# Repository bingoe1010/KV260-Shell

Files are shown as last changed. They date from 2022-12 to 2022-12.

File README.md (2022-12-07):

# KV260 Shell

<p align="center">
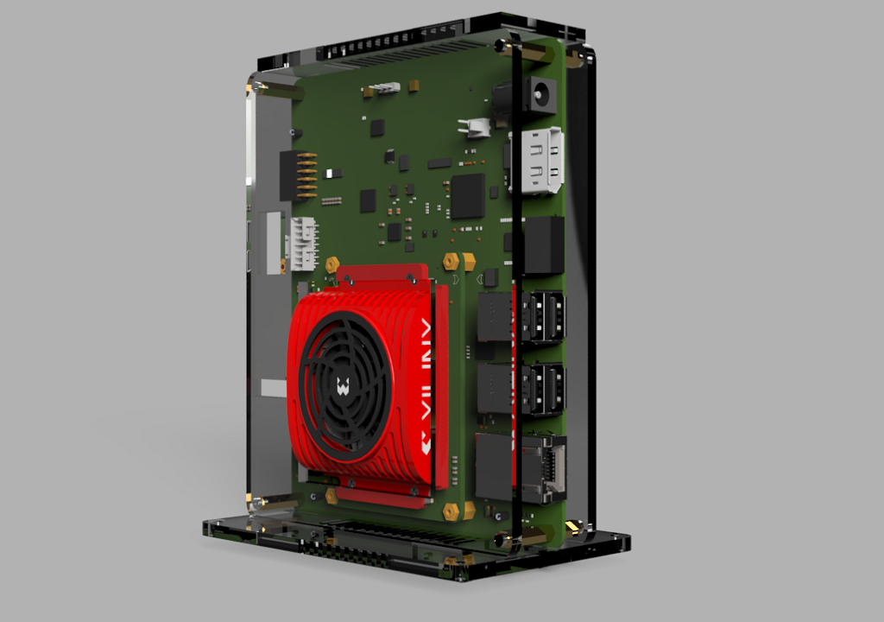
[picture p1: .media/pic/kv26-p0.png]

</p>

> This project is a vertical enclosure for a KV260 development board. The model is drawn using Fusion360 Education Edition, and the shell material can be 4mm acrylic or 3D printed structural parts. The overall cost of using the acrylic version can be controlled within 45RMB (20 RMB for acrylic material processing; Screw copper pillar about 20RMB)

[:star::star::star:中文本版介绍说明](./README_cn.md)

**3D model rendering**

<p align="center">
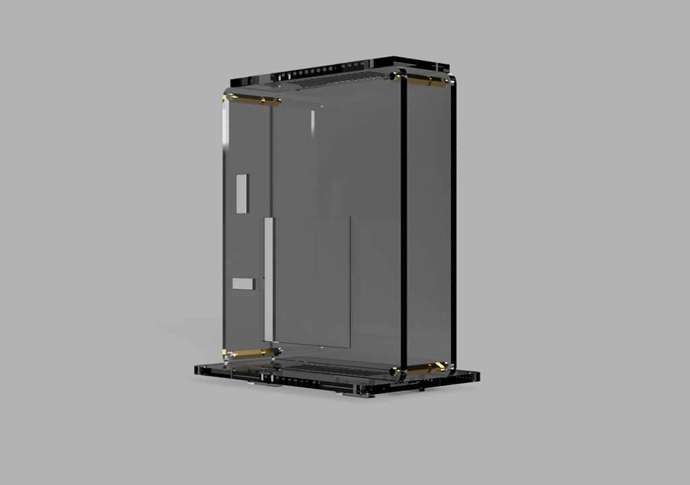
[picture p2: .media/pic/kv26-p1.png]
    
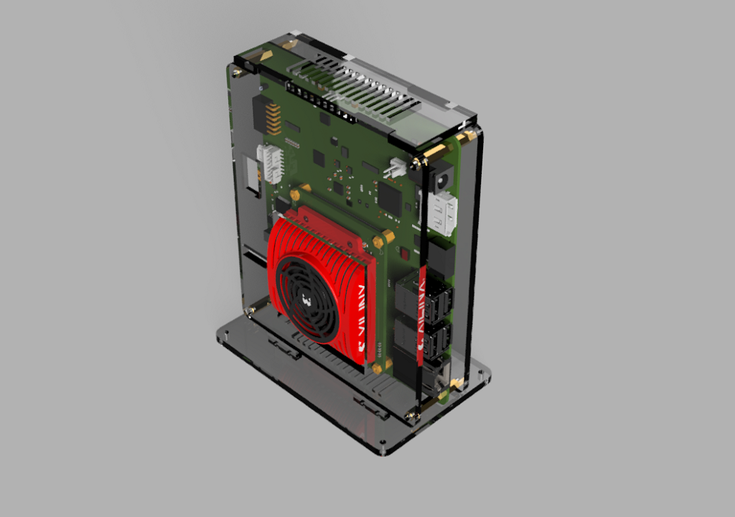
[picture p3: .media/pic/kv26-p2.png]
    
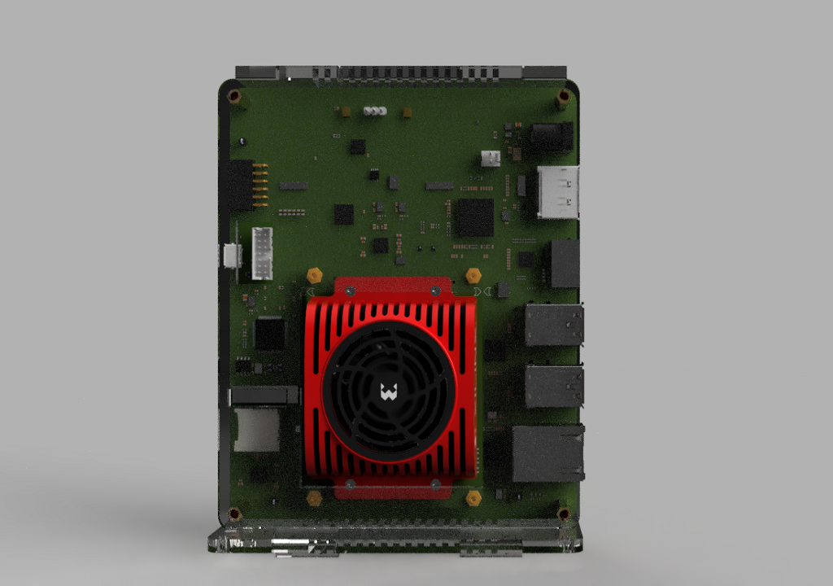
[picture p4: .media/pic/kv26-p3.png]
    
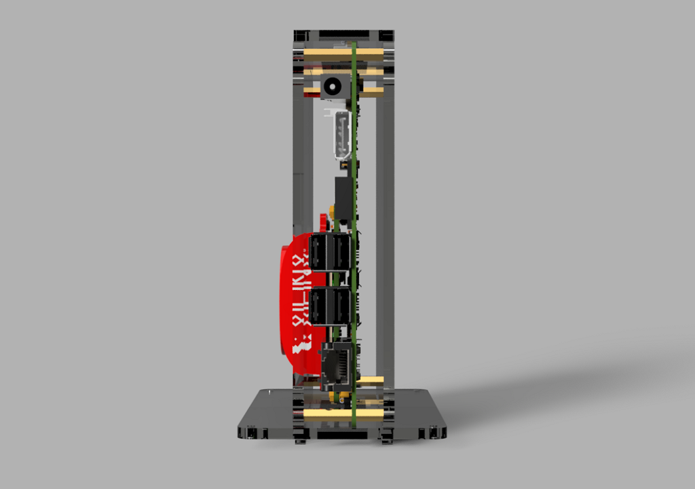
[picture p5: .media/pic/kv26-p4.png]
    
    <br>
    <sup>3D-view drawing<a href="http://https://github.com/bingxie-xpu/" target="_blank">Author:bingxie</a></sup>
</p>

## Content

1. [Description](#Description)

2. [Instruction](#Instruction)

3. [Required](#Required)

4. [Exhibition](#Exhibition)

## Description

|  **Item**  | **Description** | **Other** |
| :---: | :---: | :---: |
| **.media** | Media illustration folder | .png/.gif |
| **1.Doc**  | Details of the required copper pillar screws | .xlsx |
| **2.Stl**  | 3D printed model files | .stl |
| **3.Dxf**  | Acrylic plate cutting file | .dxf |

## Instruction

Video Link：[【KV260系列】KV260立式亚克力外壳制作](https://www.bilibili.com/video/BV1s44y1S7Lj/?vd_source=3a0f8ef7e33855035b7b41686470a16f)

```tcl
https://www.bilibili.com/video/BV1s44y1S7Lj/?vd_source=3a0f8ef7e33855035b7b41686470a16f
```

## Required

* Acrylic sheet (or 3D printed structural parts)

All DXF cutting files are in the project directory under `3. Dxf`, where `kv26_all-V2.dxf` is a two-dimensional machining diagram of all plates, as shown in the figure below. The rest of the files are 2D drawings of individual parts that you can use to build the 3D model you need.

<p align="center">
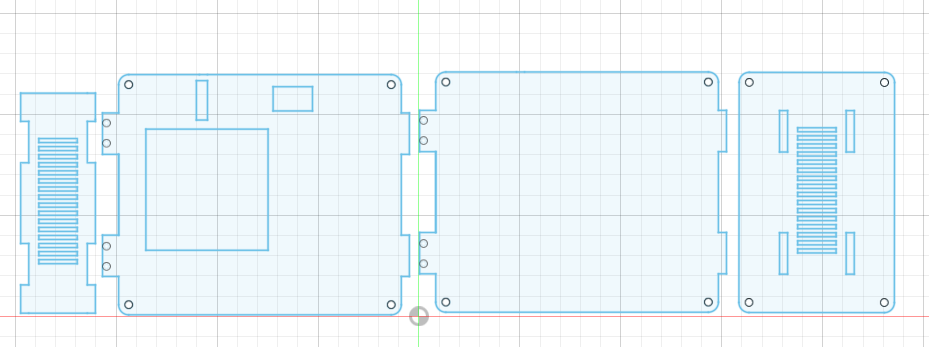
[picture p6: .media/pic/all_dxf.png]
    
    <br>
    <sup>kv26_all-V2.dxf  <a href="http://https://github.com/bingxie-xpu/" target="_blank">Author:bingxie</a></sup>
</p>

Tips.  From the left to right is`top_shell`、`front_shell`、`back_shell`、`base_shell`

* The model and quantity of copper pillar screws are shown in the following table:

| **Pattern** | **Name** | **Specification** | **Number** |
| :---: | :---: | :---: | :---: |
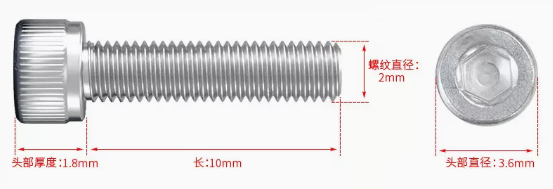
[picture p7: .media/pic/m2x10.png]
|   | **内六角螺丝** | `M2x10` | 8 |
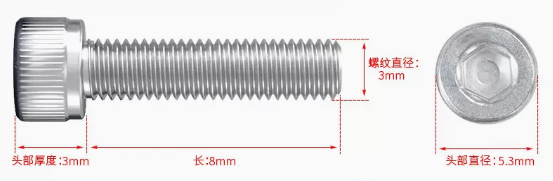
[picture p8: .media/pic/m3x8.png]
|  | **内六角螺丝** | `M3x8` | 12 |
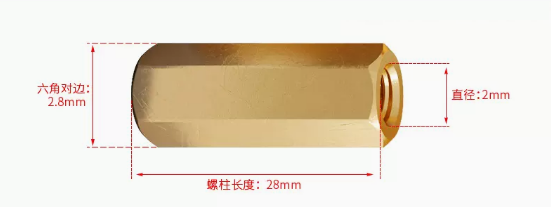
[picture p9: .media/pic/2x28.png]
|  |  **六角双通铜柱**  | `M2x28` | 4 |
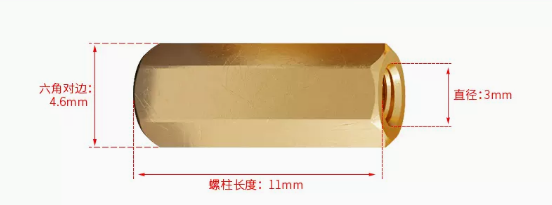
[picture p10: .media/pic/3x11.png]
|  |  **六角双通铜柱**  | `M3x11` | 4 |
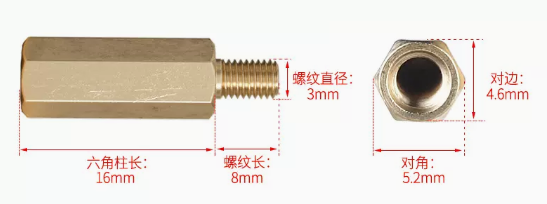
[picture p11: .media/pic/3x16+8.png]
|  |  **六角单头铜柱**  | `M3x16+8` | 4 |
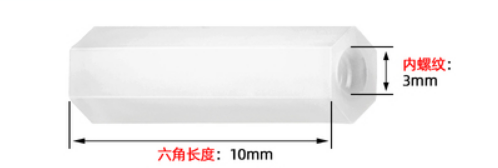
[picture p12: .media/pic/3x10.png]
|    | **尼龙六角双通柱** | `M3x10` | 4 |

Tips.  ==The nylon hexagonal double-thru column is used as a base support column, this specification is not required, and the M3x11 copper column can be used instead==)

<p align="center">
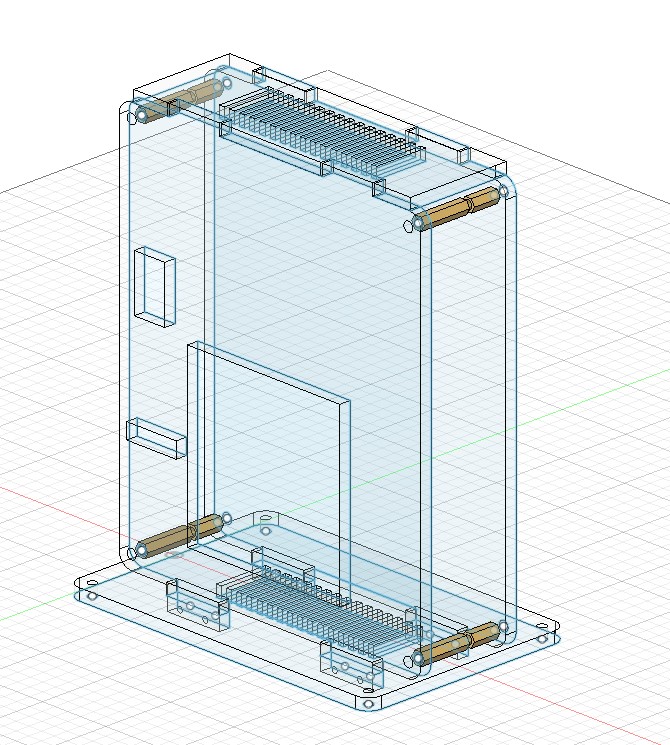
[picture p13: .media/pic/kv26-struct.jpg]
    
    <br>
    <sup>kv26-structure <a href="http://https://github.com/bingxie-xpu" target="_blank">Author:bingxie</a></sup>
</p>

## Exhibition

<p align="center">
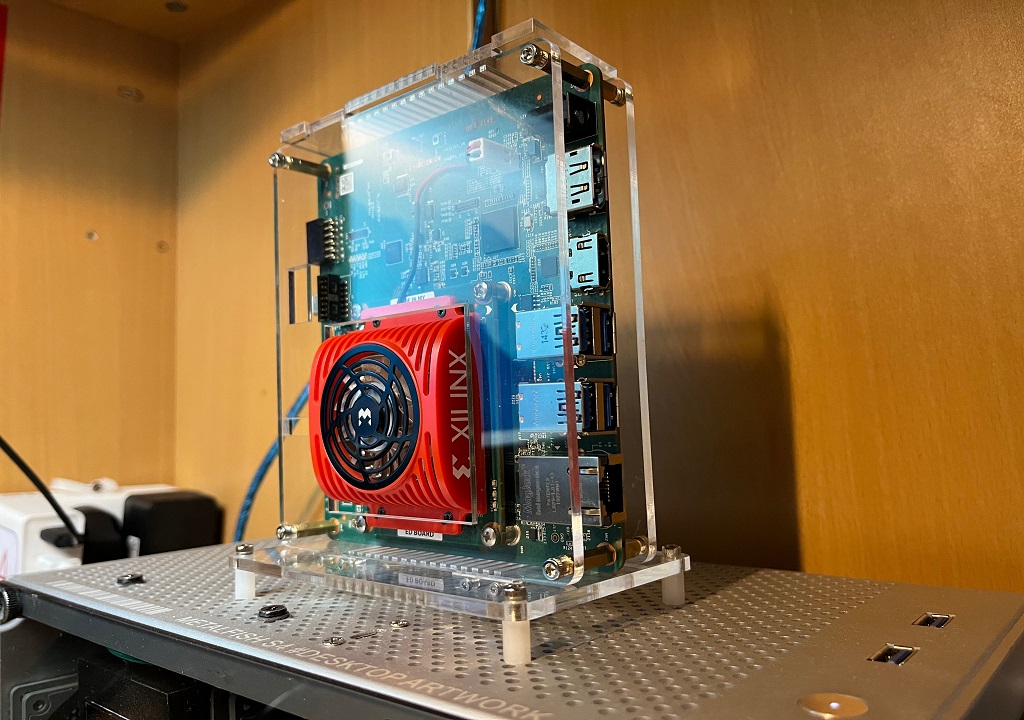
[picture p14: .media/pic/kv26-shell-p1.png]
    
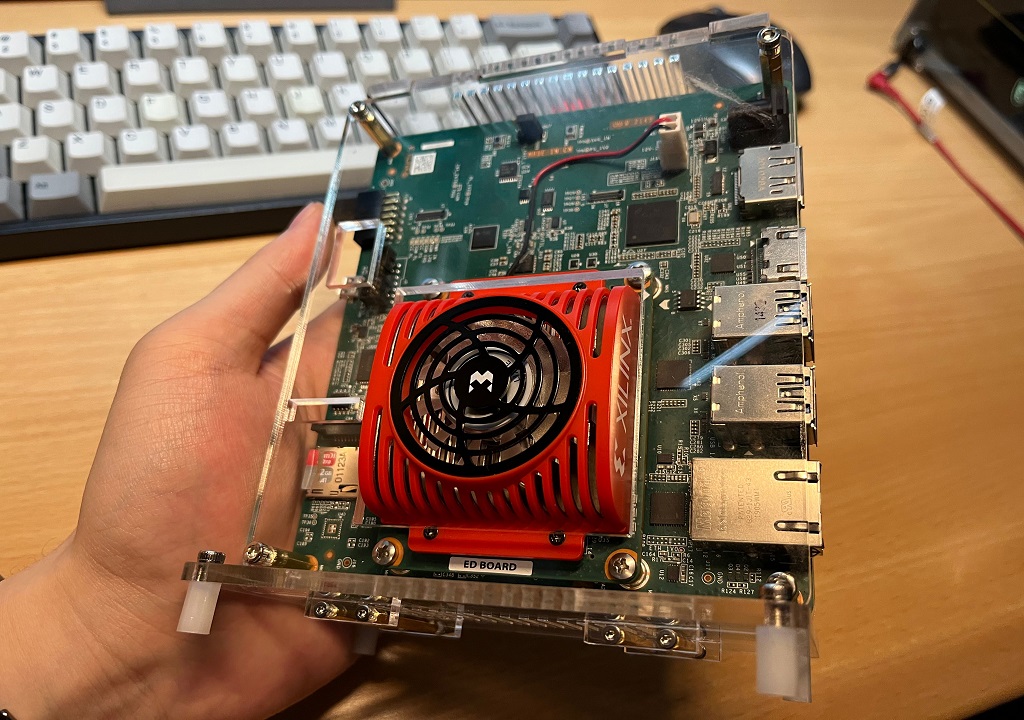
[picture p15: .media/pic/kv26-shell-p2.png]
    
    <br>
    <sup>real-view drawing<a href="http://https://github.com/bingxie-xpu/" target="_blank">Author:bingxie</a></sup>
</p>

<p align="center">
    
    <br>
    <sup>Testing Yolo v3 Singal-person <a href="http://https://github.com/bingxie-xpu" target="_blank">Author:bingxie</a></sup>
</p>

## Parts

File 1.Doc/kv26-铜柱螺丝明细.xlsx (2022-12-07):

名称 | 规格 | 数量
内六角螺丝 | M2x10 | 8
内六角螺丝 | M3x8 | 12
六角双通铜柱 | M2x28 | 4
六角双通铜柱 | M3x11 | 4
六角单头铜柱 | M3x16+8 | 4
尼龙六角双通柱 | M3x10 | 4 | 此零件为底座支撑柱，可使用M3x11的铜柱代替

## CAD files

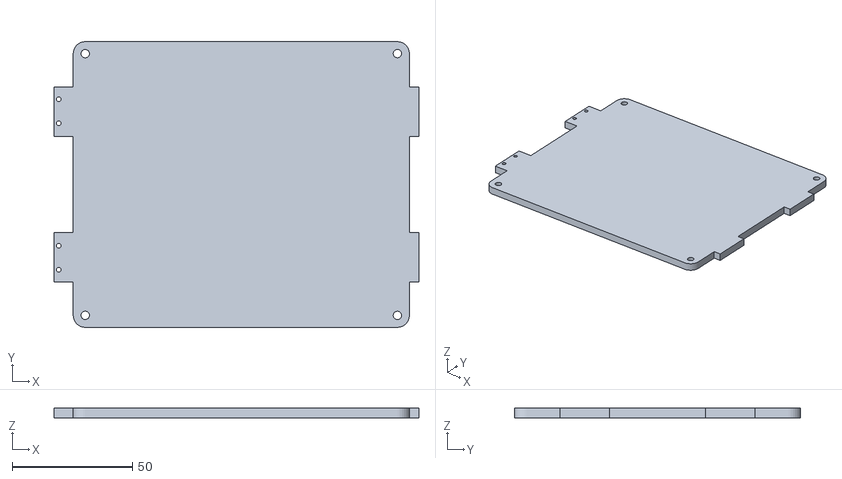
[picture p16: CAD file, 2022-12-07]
2.Stl/back_shell.stl
152.0 x 119.0 x 4.00

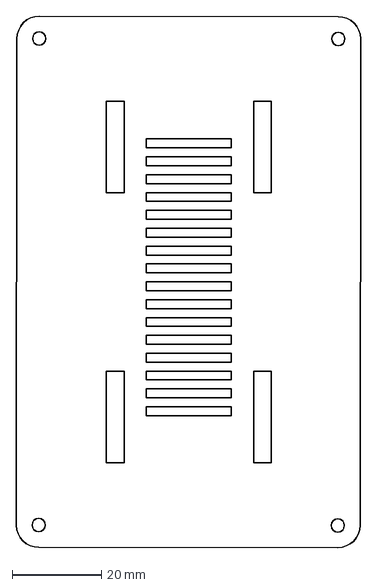
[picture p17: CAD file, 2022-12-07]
3.Dxf/base_shell-V2.dxf
77.1 x 119.1 mm

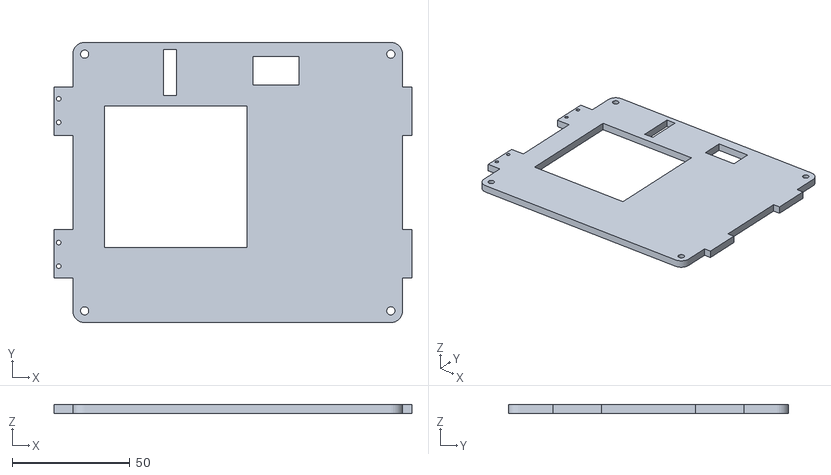
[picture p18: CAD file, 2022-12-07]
2.Stl/front_shell.stl
152.0 x 119.0 x 4.00

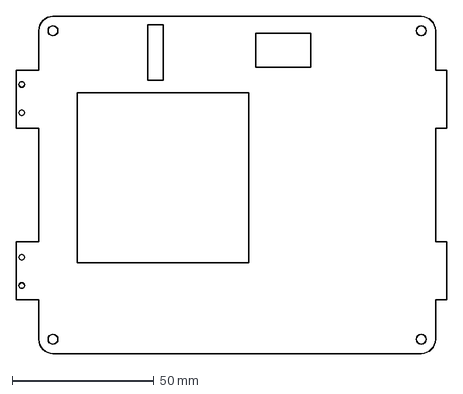
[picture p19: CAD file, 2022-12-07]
3.Dxf/front_shell-V2.dxf
152.0 x 119.0 mm

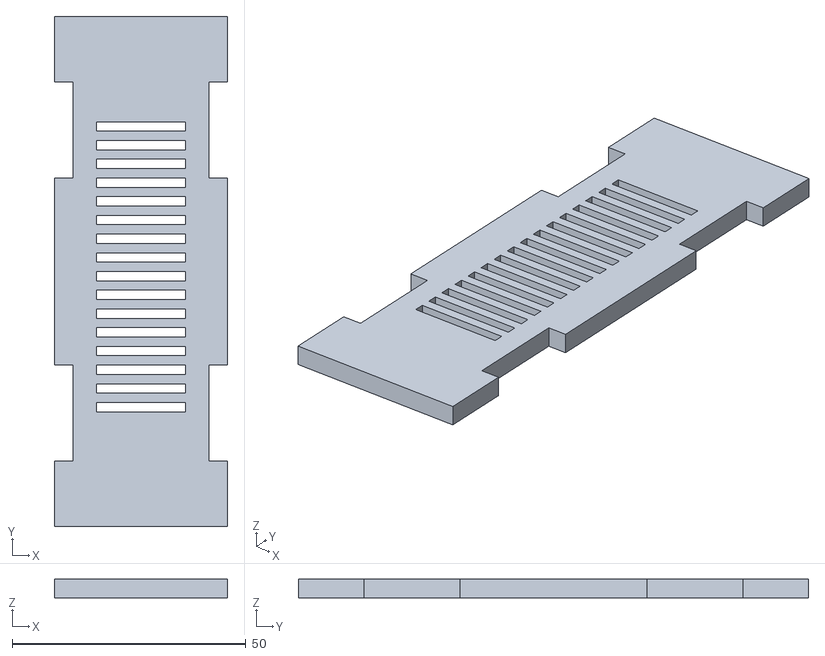
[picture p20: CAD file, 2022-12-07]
2.Stl/top_shell.stl
37.0 x 109.0 x 4.00

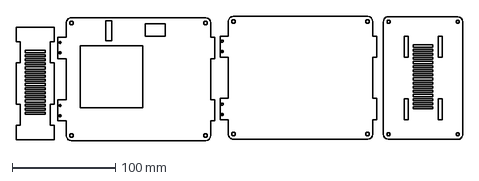
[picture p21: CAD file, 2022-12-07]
3.Dxf/kv26_all-V2.dxf
432.9 x 120.3 mm

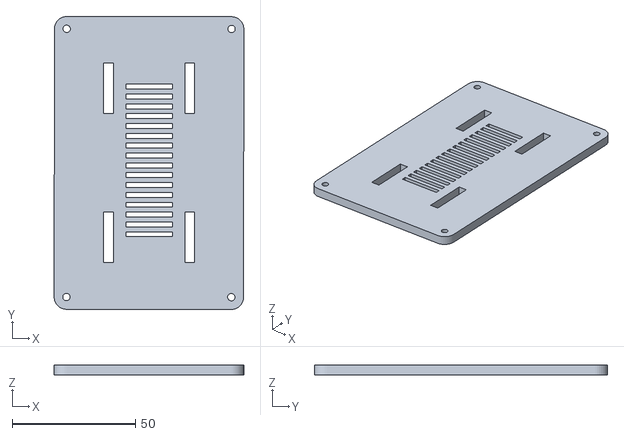
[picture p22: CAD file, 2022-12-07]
2.Stl/base_shell.stl
77.1 x 119.1 x 4.00

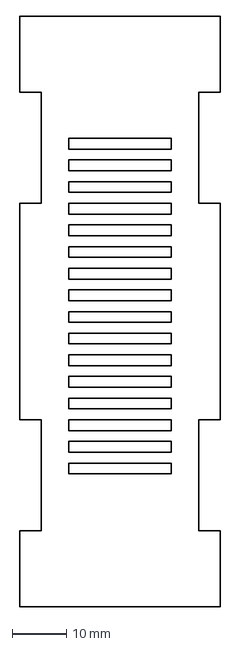
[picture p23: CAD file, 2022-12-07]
3.Dxf/top_shell-V2.dxf
37.0 x 109.0 mm

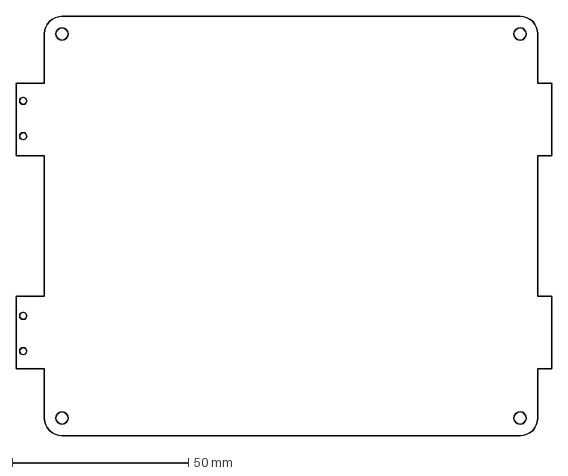
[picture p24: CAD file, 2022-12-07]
3.Dxf/back_shell-V2.dxf
152.0 x 119.0 mm
